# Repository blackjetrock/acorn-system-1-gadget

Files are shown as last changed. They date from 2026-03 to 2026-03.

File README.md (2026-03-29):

# Acorn System One Gadget

This is a small gadget that attaches to an Acorn System One. It is a Pico XL RP2350 with 48 GPIOs attached to the
expansion bus of the System One

* 60K of memory. The RP2350 emulates RAM everywhere in the memory space apart from block 0
* Tracing of addresses as code executes. This is a crude trace at the moment, but could be expanded.
* Loading of binary files from SD card into memory. For instance the monitor can be loaded from SD card and run from RAM.
* Snapshot of the entire 64K memory to an SD card file.
* A USB CLI that can drive the gadget
* An OLED display and three keys, these do nothing at the moment.
* Reset from the USB CLI
* Powering of the System One from the USB supply of the Pico. The regulator has to be removed for this to work. Power can
  come from a host computer if the USB CLI is used, or a battery power pack for portability.



On a system 1 you can load a slightly modified COS and BASIC into memory and run it:



The COS is modified to move the 6522 into RAM so that the keyboard can be driven from the USB CLI. The screen is captured by reading screen memory and also emulating som eof the functions of the 6845 CRT controller.

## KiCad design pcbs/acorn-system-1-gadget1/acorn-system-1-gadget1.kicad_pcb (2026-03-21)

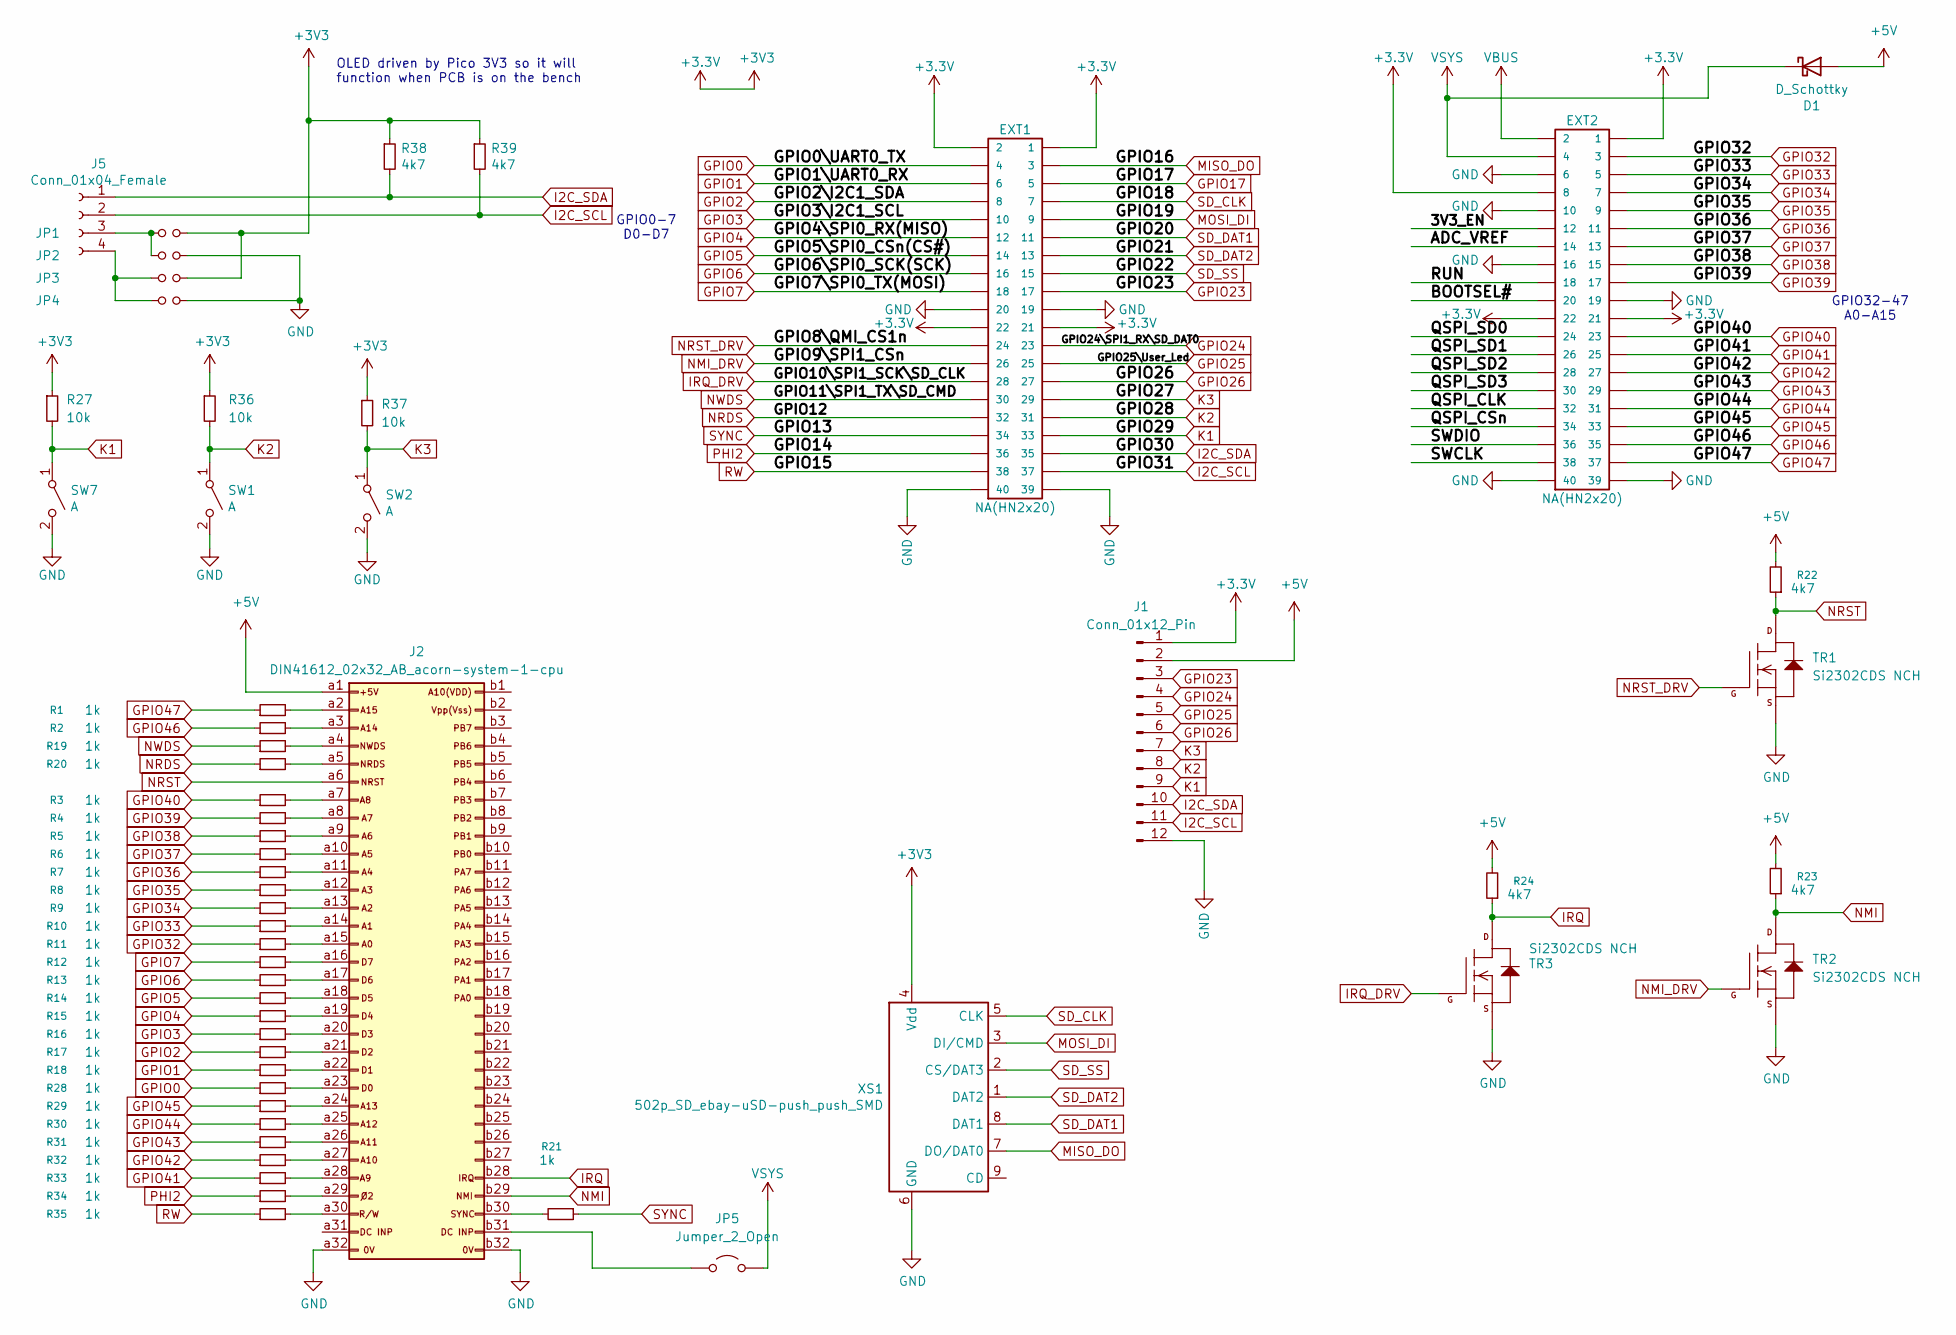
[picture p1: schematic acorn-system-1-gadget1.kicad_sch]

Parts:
D1: D_Schottky; D_SOD-123
EXT1, EXT2: NA(HN2x20); PinSocket_2x20_P2.54mm_Vertical
J1: Conn_01x12_Pin; PinHeader_1x12_P2.54mm_Vertical
J2: DIN41612_02x32_AB_acorn-system-1-cpu; DIN41612_Q_2x32_Female_Horizontal_THT
J5: Conn_01x04_Female; PinHeader_1x04_P2.54mm_Vertical
JP1, JP2, JP3, JP4: Jumper_NO_Small; SolderJumper-2_P1.3mm_Open_TrianglePad1.0x1.5mm
JP5: Jumper_2_Open; PinHeader_1x02_P2.54mm_Vertical
R1, R2, R3, R4, R5, R6, R7, R8, R9, R10, R11, R12, R13, R14, R15, R16, R17, R18, R19, R20, R21, R28, R29, R30, R31, R32, R33, R34, R35: 1k; R_0805_2012Metric_Pad1.20x1.40mm_HandSolder
R22, R23, R24, R38, R39: 4k7; R_0805_2012Metric_Pad1.20x1.40mm_HandSolder
R27, R36, R37: 10k; R_0805_2012Metric
SW1, SW2, SW7: A; SW_PUSH_6mm
TR1, TR2, TR3: Si2302CDS NCH; SOT-23
XS1: 502p_SD_ebay-uSD-push_push_SMD; Conn_uSDcard

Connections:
+3.3V: EXT1.1, EXT1.2, EXT1.21, EXT1.22, EXT2.1, EXT2.8, EXT2.21, EXT2.22, J1.1, JP1.2, JP3.2, R27.1, R36.1, R37.1, R38.1, R39.1, XS1.4 (Vdd)
+5V: D1.2 (A), J1.2, J2.a1, R22.2, R23.2, R24.2
/3V3_EN: EXT2.12
/ADC_VREF: EXT2.14
/BOOTSEL#: EXT2.20
/QSPI_CLK: EXT2.32
/QSPI_CSn: EXT2.34
/QSPI_SD0: EXT2.24
/QSPI_SD1: EXT2.26
/QSPI_SD2: EXT2.28
/QSPI_SD3: EXT2.30
/RUN: EXT2.18
/SWCLK: EXT2.38
/SWDIO: EXT2.36
GND: EXT1.19, EXT1.20, EXT1.39, EXT1.40, EXT2.6, EXT2.10, EXT2.16, EXT2.19, EXT2.39, EXT2.40, J1.12, J2.a32, J2.b32, JP2.2, JP4.2, SW1.2 (B), SW2.2 (B), SW7.2 (B), TR1.2 (S), TR2.2 (S), TR3.2 (S), XS1.6 (GND)
GPIO0: EXT1.4, R28.1
GPIO1: EXT1.6, R18.1
GPIO2: EXT1.8, R17.1
GPIO3: EXT1.10, R16.1
GPIO4: EXT1.12, R15.1
GPIO5: EXT1.14, R14.1
GPIO6: EXT1.16, R13.1
GPIO7: EXT1.18, R12.1
GPIO17: EXT1.5
GPIO23: EXT1.17, J1.3
GPIO24: EXT1.23, J1.4
GPIO25: EXT1.25, J1.5
GPIO26: EXT1.27, J1.6
GPIO32: EXT2.3, R11.1
GPIO33: EXT2.5, R10.1
GPIO34: EXT2.7, R9.1
GPIO35: EXT2.9, R8.1
GPIO36: EXT2.11, R7.1
GPIO37: EXT2.13, R6.1
GPIO38: EXT2.15, R5.1
GPIO39: EXT2.17, R4.1
GPIO40: EXT2.23, R3.1
GPIO41: EXT2.25, R33.1
GPIO42: EXT2.27, R32.1
GPIO43: EXT2.29, R31.1
GPIO44: EXT2.31, R30.1
GPIO45: EXT2.33, R29.1
GPIO46: EXT2.35, R2.1
GPIO47: EXT2.37, R1.1
I2C_SCL: EXT1.37, J1.11, J5.2, R39.2
I2C_SDA: EXT1.35, J1.10, J5.1, R38.2
IRQ: J2.b28, R24.1, TR3.3 (D)
IRQ_DRV: EXT1.28, TR3.1 (G)
K1: EXT1.33, J1.9, R27.2, SW7.1 (A)
K2: EXT1.31, J1.8, R36.2, SW1.1 (A)
K3: EXT1.29, J1.7, R37.2, SW2.1 (A)
MISO_DO: EXT1.3, XS1.7 (DO/DAT0)
MOSI_DI: EXT1.9, XS1.3 (DI/CMD)
NMI: J2.b29, R23.1, TR2.3 (D)
NMI_DRV: EXT1.26, TR2.1 (G)
NRDS: EXT1.32, R20.1
NRST: J2.a6, R22.1, TR1.3 (D)
NRST_DRV: EXT1.24, TR1.1 (G)
NWDS: EXT1.30, R19.1
unnamed: J2.a2, R1.2
unnamed: J2.a3, R2.2
unnamed: J2.a4, R19.2
unnamed: J2.a5, R20.2
unnamed: J2.a7, R3.2
unnamed: J2.a8, R4.2
unnamed: J2.a9, R5.2
unnamed: J2.a10, R6.2
unnamed: J2.a11, R7.2
unnamed: J2.a12, R8.2
unnamed: J2.a13, R9.2
unnamed: J2.a14, R10.2
unnamed: J2.a15, R11.2
unnamed: J2.a16, R12.2
unnamed: J2.a17, R13.2
unnamed: J2.a18, R14.2
unnamed: J2.a19, R15.2
unnamed: J2.a20, R16.2
unnamed: J2.a21, R17.2
unnamed: J2.a22, R18.2
unnamed: J2.a23, R28.2
unnamed: J2.a24, R29.2
unnamed: J2.a25, R30.2
unnamed: J2.a26, R31.2
unnamed: J2.a27, R32.2
unnamed: J2.a28, R33.2
unnamed: J2.a29, R34.2
unnamed: J2.a30, R35.2
unnamed: J2.b30, R21.2
unnamed: J2.b31, JP5.1 (A)
unnamed: J5.3, JP1.1, JP2.1
unnamed: J5.4, JP3.1, JP4.1
PHI2: EXT1.36, R34.1
RW: EXT1.38, R35.1
SD_CLK: EXT1.7, XS1.5 (CLK)
SD_DAT1: EXT1.11, XS1.8 (DAT1)
SD_DAT2: EXT1.13, XS1.1 (DAT2)
SD_SS: EXT1.15, XS1.2 (CS/DAT3)
SYNC: EXT1.34, R21.1
VBUS: EXT2.2
VSYS: D1.1 (K), EXT2.4, JP5.2 (B)

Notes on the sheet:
OLED driven by Pico 3V3 so it will function when PCB is on the bench
GPIO0-7 D0-D7
GPIO32-47 A0-A15

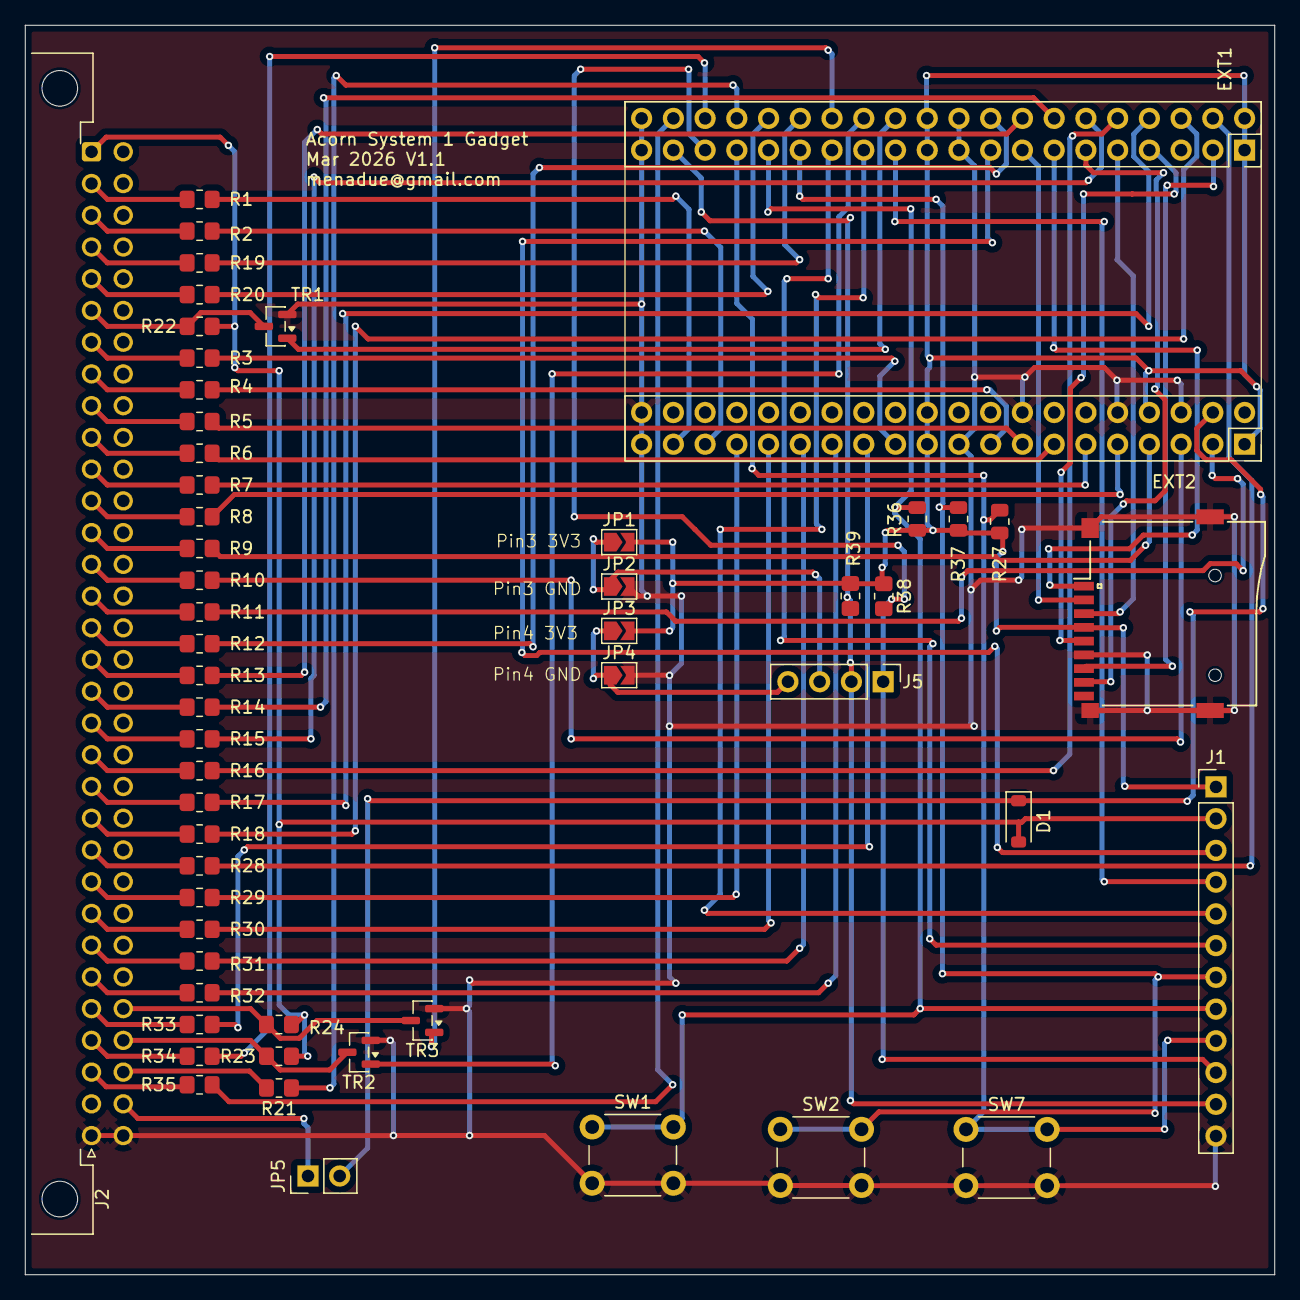
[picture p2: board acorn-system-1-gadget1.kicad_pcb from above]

Board: 2 copper layers, 100.0 x 100.0 mm, 55 parts (0 on the bottom side), 86 nets.

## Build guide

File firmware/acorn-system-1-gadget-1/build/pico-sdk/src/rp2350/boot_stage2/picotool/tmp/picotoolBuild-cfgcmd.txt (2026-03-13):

cmd='/usr/bin/cmake;--no-warn-unused-cli;-DCMAKE_MAKE_PROGRAM:FILEPATH=/usr/bin/gmake;-DPICO_SDK_PATH:FILEPATH=/home/menadue/pico/pico-sdk;-DPICOTOOL_NO_LIBUSB=1;-DPICOTOOL_FLAT_INSTALL=1;-DCMAKE_INSTALL_PREFIX=/home/menadue/tree/github/acorn-system-1-gadget/firmware/acorn-system-1-gadget-1/build/_deps;-DCMAKE_RULE_MESSAGES=OFF;-DCMAKE_INSTALL_MESSAGE=NEVER;-GUnix Makefiles;-S;<SOURCE_DIR><SOURCE_SUBDIR>;-B;<BINARY_DIR>'

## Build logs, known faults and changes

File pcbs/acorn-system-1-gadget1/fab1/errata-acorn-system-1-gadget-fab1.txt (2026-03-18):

1. Signals to SD card holder reversed.
2. Run BUS power to edge connector through jumper for USB power ption.

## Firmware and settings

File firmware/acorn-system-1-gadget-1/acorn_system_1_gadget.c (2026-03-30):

//////////////////////////////////////////////////////////////////////////////
//
// Acorn System 1 Memory Emulator
//
////////////////////////////////////////////////////////////////////////////////
//
// Emulates memory
//
// Set up to emulate 60K of memory, only page 0 is not emulated.
// PROMs removed and emulated
//
//
////////////////////////////////////////////////////////////////////////////////

#include "switches.h"
#include "version.h"

#pragma GCC diagnostic ignored "-Wwrite-strings"

#include <ctype.h>
#include <math.h>
#include <stdarg.h>
#include <stdio.h>
#include <stdlib.h>
#include <string.h>
#include <stdint.h>

#include "pico/stdlib.h"
#include "hardware/pio.h"
#include "hardware/dma.h"
#include "hardware/irq.h"
#include "hardware/flash.h"
#include "hardware/clocks.h"
#include "hardware/structs/bus_ctrl.h"

#define DEBUG_STOP_LOOP while(1) {}

// Some logic to analyse:

#include "hardware/structs/pwm.h"
#include "pico/multicore.h"
#include "pico/bootrom.h"

#include "oled.h"
#include "sdcard.h"

#include "menu.h"

////////////////////////////////////////////////////////////////////////////////

#define MAX_FILE_LINE 200

////////////////////////////////////////////////////////////////////////////////
//
#define ACORN_PORTD   0x2E21

////////////////////////////////////////////////////////////////////////////////
//
// VDU registers
#define NUM_VDU_REGS 20

volatile uint8_t vdu_reg[NUM_VDU_REGS];
volatile uint8_t vdu_addr = 0xcc;

#define VDU_REG_HOR_DISP  1
#define VDU_REG_VER_DISP  6

#define VDU_REG_STARTH   12
#define VDU_REG_STARTL   13
#define VDU_REG_CURSRH   14
#define VDU_REG_CURSRL   15

#define VDU_START_ADDRESS (vdu_reg[VDU_REG_STARTH]*256+vdu_reg[VDU_REG_STARTL])
#define VDU_CURSR_ADDRESS (vdu_reg[VDU_REG_CURSRH]*256+vdu_reg[VDU_REG_CURSRL])
#define VDU_NUM_CHARS     (vdu_reg[VDU_REG_HOR_DISP]*vdu_reg[VDU_REG_VER_DISP])

////////////////////////////////////////////////////////////////////////////////
//
// Tracing of processor accesses
//

#define TRACE_ON 1

// How many addresses are traced
#define TRACE_N   32

volatile int trace_i = 0;
volatile int trace_running = 0;

volatile uint16_t trace_addr[TRACE_N];
volatile uint8_t trace_value[TRACE_N];
volatile char trace_type[TRACE_N];

////////////////////////////////////////////////////////////////////////////////

void prompt(void);
void serial_help(void);

////////////////////////////////////////////////////////////////////////////////

// How much RAM to display 
#define RAM_SIZE 1024

// Shadow of entire memory space
#define MEM_SIZE 65536

volatile uint8_t mem_data[MEM_SIZE];

#define ADDRESS_MASK  0xFFFF
#define WINDOW_START  0x8000

////////////////////////////////////////////////////////////////////////////////



////////////////////////////////////////////////////////////////////////////////

// Value that can be set from the keyboard
// Can be entered as hex or decimal

#define PAR_TYPE_DEC 0

int parameter = 0;
int keypress = 0;

#define TEXT_PARAMETER_LEN 40
char text_parameter[TEXT_PARAMETER_LEN+1] = "";

////////////////////////////////////////////////////////////////////////////////
//
// GPIOs
//

const int PIN_D0        =  0;
const int PIN_D1        =  1;
const int PIN_D2        =  2;
const int PIN_D3        =  3;
const int PIN_D4        =  4;
const int PIN_D5        =  5;
const int PIN_D6        =  6;
const int PIN_D7        =  7;

const int PIN_NRST_DRV  =  8;
const int PIN_NMI_DRV   =  9;
const int PIN_IRQ_DRV   =  10;
const int PIN_NWDS      =  11;
const int PIN_NRDS      =  12;
const int PIN_SYNC      =  13;
const int PIN_PHI2      =  14;
const int PIN_RW        =  15;

#define PIN_BITNUM_NWDS    11
#define PIN_BITNUM_NRDS    12

// SD card GPIOs here
const int PIN_K3        =  27;
const int PIN_K2        =  28;
const int PIN_K1        =  29;


const int PIN_A0        =  32;
const int PIN_A1        =  33; 
const int PIN_A2        =  34; 
const int PIN_A3        =  35; 
const int PIN_A4        =  36; 
const int PIN_A5        =  37; 
const int PIN_A6        =  38; 
const int PIN_A7        =  39; 
const int PIN_A8        =  40; 
const int PIN_A9        =  41; 
const int PIN_A10       =  42; 
const int PIN_A11       =  43; 
const int PIN_A12       =  44; 
const int PIN_A13       =  45; 
const int PIN_A14       =  46; 
const int PIN_A15       =  47; 


////////////////////////////////////////////////////////////////////////////////
//
// Chris oddy display
//

uint8_t app1[] =
  {
    0xa2, 0x07, 0xbd, 0x10, 0x80, 0x95, 0x10, 0xca, 0x10, 0xf8, 0x20, 0x0c, 0xfe, 0x4c, 0xfb, 0xfe,
    0x00, 0x77, 0x58, 0x5c, 0x50, 0x54, 0x00, 0x30,
  };


//------------------------------------------------------------------------------

uint8_t *app_list[] =
  {
    app1,
  };

////////////////////////////////////////////////////////////////////////////////

void set_gpio_output(const int gpio)
{
  gpio_init(gpio);
  gpio_set_dir(gpio, GPIO_OUT);
}

void set_gpio_input(const int gpio)
{
  gpio_init(gpio);
  gpio_set_dir(gpio, GPIO_IN);
}

////////////////////////////////////////////////////////////////////////////////

////////////////////////////////////////////////////////////////////////////////

void run_mount(void) {
  //    const char *arg = chk_dflt_log_drv(argc, argv);
  const char *arg = "0:";
  if (!arg)
        return;
    sd_card_t *sd_card_p = sd_get_by_drive_prefix(arg);
    if (!sd_card_p) {
        printf("Unknown logical drive id: \"%s\"\n", arg);
        return;
    }
    FATFS *fs_p = &sd_card_p->state.fatfs;
    FRESULT fr = f_mount(fs_p, arg, 1);
    if (FR_OK != fr) {
        printf("f_mount error: %s (%d)\n", FRESULT_str(fr), fr);
        return;
    }
    sd_card_p->state.mounted = true;
}

void run_unmount(void) {
  //    const char *arg = chk_dflt_log_drv(argc, argv);
  const char *arg = "0:";
  
  if (!arg)
        return;

    sd_card_t *sd_card_p = sd_get_by_drive_prefix(arg);
    if (!sd_card_p) {
        printf("Unknown logical drive id: \"%s\"\n", arg);
        return;
    }    
    FRESULT fr = f_unmount(arg);
    if (FR_OK != fr) {
        printf("f_unmount error: %s (%d)\n", FRESULT_str(fr), fr);
        return;
    }
    sd_card_p->state.mounted = false;
    sd_card_p->state.m_Status |= STA_NOINIT;  // in case medium is removed
}

////////////////////////////////////////////////////////////////////////////////

void display_ram_at(uint8_t *dat)
{
  printf("\n");
  
  for(int z = 0; z<RAM_SIZE; z++)
    {
      int byte = 0;
      
      if( (z % 8) == 0)
	{
	  printf("\n%03X: ", z);
	}
      
      printf("%02X ", *(dat++));
    }
  
  printf("\n");

}

////////////////////////////////////////////////////////////////////////////////
//
// Flash data
//
// We have several flash program slots.
// Slots are in the top 1Mbyte of flash
//
// The flash has to be erased in 4096 byte aligned blocks
// Writes can be 256 byte aligned but due to erase being 4096 we use that slot size.

// Program and dat aram is stored at the same time, so it is a snapshot of the entire
// RAM. RAM plkus program is 256 bytes.


#define FLASH_PROGRAM_DATA_SIZE         256
#define FLASH_PROGRAM_SLOT_SIZE         4096
#define FLASH_PROGRAM_SLOT_AREA_SIZE    (1000*1024)
#define FLASH_PROGRAM_NUM_SLOTS         (FLASH_PROGRAM_SLOT_AREA_SIZE / FLASH_PROGRAM_SLOT_SIZE)

#define FLASH_SLOT_OFFSET (1024*1024)
uint8_t *flash_slot_contents   = (uint8_t *) (XIP_BASE + FLASH_SLOT_OFFSET);

// general buffer for flash read and write
uint8_t slot_buffer[FLASH_PROGRAM_DATA_SIZE];


////////////////////////////////////////////////////////////////////////////////
//
// Flash write/erase
//
////////////////////////////////////////////////////////////////////////////////

// Erase a slot
void erase_slot(int n)
{
  flash_range_erase(FLASH_SLOT_OFFSET+n*FLASH_PROGRAM_SLOT_SIZE, FLASH_PROGRAM_SLOT_SIZE);
}

// Checksum a slot
int checksum_slot(int slot_num)
{
  int csum = 0;

  for(int i=0; i<FLASH_PROGRAM_DATA_SIZE; i++)
    {
      csum += *(flash_slot_contents+slot_num*FLASH_PROGRAM_SLOT_SIZE+i);
    }

  return(csum);
}
void cli_erase_program_slot(void)
{
  printf("\nErasing program slot %d...", parameter);
  erase_slot(parameter);
  printf("\ndone.\n");
}

void cli_display_program_slot(void)
{
  
  printf("\nSlot %d\n", parameter);

  // First dump in hex
  display_ram_at(flash_slot_contents+parameter*FLASH_PROGRAM_SLOT_SIZE);

  printf("\n\n");
}

void cli_display_vdu_regs(void)
{
  printf("\nVDU Regs\n");

  printf("\nVDU_START:     %04X", VDU_START_ADDRESS);
  printf("\nVDU_NUM_CHARS: %04X (%d)", VDU_NUM_CHARS, VDU_NUM_CHARS);
  
  printf("\nAddr:%02X", vdu_addr);

  for(int i=0; i<NUM_VDU_REGS; i++)
    {
      printf("\n%02X:%02X", i, vdu_reg[i]);
    }

  printf("\n");
}


////////////////////////////////////////////////////////////////////////////////


void cli_get_vdu(void)
{
  // Display the VDU screen area
  //

  printf("\n/--------------------------------------------------------------------------------\\");
  
  for(int i=0; i< 2000; i++)
    {
      if( (i % 80) == 0 )
        {
          if( i != 0 )
            {
              printf("|");
            }
          
          printf("\n|");
        }
      
      printf("%c", mem_data[0x1000+i]);
    }

  printf("|\n\\--------------------------------------------------------------------------------/");
  printf("\n");
}
////////////////////////////////////////////////////////////////////////////////

uint8_t screen[8192];

int cursor_on = 1;
int cursor_counter = 0;

void update_screen(void)
{
  // Cursor Position (Row, Col): ESC [ <row>;<col> H (e.g., 10,10)
  // Save Cursor Position: ESC 7 (DECSC)
  // Restore Cursor Position: ESC 8 (DECRC)

  cursor_counter++;

  if( cursor_counter > 12 )
    {
      cursor_on = !cursor_on;
      cursor_counter = 0;
    }
  
  // Compare screen buffer with memory, update any changes
  int x = 0;
  int y = 0;

  int vdu_start = VDU_START_ADDRESS;
  int vdu_addr = (vdu_start & 0x07FF) | 0x1000;
  int cur_addr = (VDU_CURSR_ADDRESS & 0x07FF) | 0x1000;
  
  printf("%c7", 27);
  printf("%c[?25l", 27);
  
  for(int i=0; i< 2000; i++)
    {
      if( mem_data[vdu_addr] != screen[i],1 )
        {

          printf("%c[%d;%dH", 27, y+2, x+2);
          if( cur_addr == vdu_addr )
            {
              if( cursor_on )
                {
                  printf("%c", '_');
                }
              else
                {
                  printf("%c", mem_data[vdu_addr]);
                }
            }
          else
            {
              printf("%c", mem_data[vdu_addr]);
            }
          
          //screen[i] = mem_data[vdu_addr];
        }

      vdu_addr = ((vdu_addr+1) & 0x07ff) | 0X1000;

      x++;
      
      if( x >= 80 )
        {
          x = 0;
          y++;
        }
    }
  
  printf("%c8", 27);
  printf("%c[?25h", 27);
}

//------------------------------------------------------------------------------

void cli_vdu_loop(void)
{
  int done = 0;
  int  key;
  
  printf("\nVDU Loop...\n");

  for(int i=0; i<200; i++)
    {
      printf("\n");
    }
  
  // Inital screen display
  
  cli_get_vdu();
  
  while(!done)
    {
      update_screen();
      
      if( ((key = getchar_timeout_us(1000)) != PICO_ERROR_TIMEOUT))
        {
          switch(key)
            {
            case '_':
              cli_get_vdu();
              break;
              
            case 27:
              done = 1;            
              printf("\nExit from VDU Loop\n");
              break;

            default:
              // Send to Acorn
              mem_data[ACORN_PORTD] = key | 0x80;
              sleep_us(100);
              mem_data[ACORN_PORTD] = key;
              break;
            }
	}
    }
}

////////////////////////////////////////////////////////////////////////////////
//
// Load app, index is parameter
//

void cli_load_app(void)
{
  uint8_t *app_ptr;
  int num_apps = (sizeof(app_list) / sizeof(uint8_t *));
  
  printf("\n%d apps", num_apps);
  
  if( (parameter >= 0) && (parameter < num_apps) )
    {
      app_ptr = app_list[parameter];
      
      memcpy((void *)&(mem_data[0x8000]), (void *)app_list[parameter], sizeof(app1));

      printf("\nLoaded app %d", parameter);
    }
  else
    {
      printf("\nParameter out of range");
    }
  

}

////////////////////////////////////////////////////////////////////////////////

void cli_boot_mass(void)
{
  reset_usb_boot(0,0);
}

void cli_do_reset(void)
{
  printf("\nResetting...");
  gpio_put(PIN_NRST_DRV, 1);
  sleep_ms(50);
  gpio_put(PIN_NRST_DRV, 0);

  printf("\nDone");
  
}
////////////////////////////////////////////////////////////////////////////////
//
// Scans the directory and works out the next file number to use
//
// Leaves max_filenum with that value
//
////////////////////////////////////////////////////////////////////////////////

#define FILE_NAME_FORMAT "as1%04d.bin"
#define INFO_FILE_NAME_FORMAT "as1%04d.inf"

#define FILE_NAME_SCAN   "as1%d.bin"
#define FILE_NAME_GLOB   "as1*.bin"

int find_next_file_number(void)
{
  int file_n = 0;
  int num_listfiles = 0;
  int i;
  
  char cwdbuf[FF_LFN_BUF] = {0};
  FRESULT fr;
  char const *p_dir;

  //DEBUG_STOP;

  printf("\nAttempting to cd to directory...");
  if( !cd_to_dir(FILES_DIR) )
    {
      unmount_sd();
      return(0);
    }

  printf("\nGetting cwd...");
  fr = f_getcwd(cwdbuf, sizeof cwdbuf);

  // printf will print to console
  if (FR_OK != fr)
    {
      printf("f_getcwd error: %s (%d)\n", FRESULT_str(fr), fr);
      return(0);
    }
  
  p_dir = cwdbuf;

  printf("\nFile num search: %s\n", p_dir);
  
  DIR dj;      /* Directory object */
  FILINFO fno; /* File information */

  memset(&dj, 0, sizeof dj);
  memset(&fno, 0, sizeof fno);

  max_filenum = 0;
  
  fr = f_findfirst(&dj, &fno, p_dir, FILE_NAME_GLOB);

  if (FR_OK != fr)
    {
      printf("f_findfirst error: %s (%d)\n", FRESULT_str(fr), fr);
      return(0);
    }
  
  while( (fr == FR_OK) && fno.fname[0])
    { 
      if (fno.fattrib & AM_DIR)
	{
	  // Directory, we ignore these
	}
      else
	{
	  int filenum;
	  sscanf(fno.fname, FILE_NAME_SCAN, &filenum);

	  if( filenum > max_filenum )
	    {
	      max_filenum = filenum;
	    }
	}
       
      fr = f_findnext(&dj, &fno); /* Search for next item */
    }
  
  f_closedir(&dj);

  printf("\nFound next file number %d", max_filenum);
  return(1);
}

////////////////////////////////////////////////////////////////////////////////
//
// Writes the buffer to a file.
// Deletes any file that exists with the same name so that the resulting
// file is the same size as the buffer
// Searches the card directory for the highest file number and uses the next one
//
////////////////////////////////////////////////////////////////////////////////

void core_writefile(int address, int length)
{
  char filename[20];
  char info_filename[20];
  int i;
  FRESULT fr;
  FIL fp;
  size_t bytes_written = 0;
  char line[40];

  //DEBUG_STOP

  printf("\nWriting file to SD card");
  mount_sd();

  if( !cd_to_dir(FILES_DIR) )
    {
      unmount_sd();
      return;
    }

  find_next_file_number();
  sprintf(filename,      FILE_NAME_FORMAT,      ++max_filenum);
  sprintf(info_filename, INFO_FILE_NAME_FORMAT,   max_filenum);

  printf("\nWriting to %s", filename);
  
  oled_clear_display(&oled0);
  oled_set_xy(&oled0, 0, 0);
  oled_display_string(&oled0, "Writing");
  oled_set_xy(&oled0, 0, 8);
  oled_display_string(&oled0, filename);
  
  // Open file for writing
  fr = f_open(&fp, filename, FA_CREATE_NEW | FA_WRITE);

  if (FR_OK != fr && FR_EXIST != fr)
    {
      printf("\nOpen error");
      //      oled_error("Open error");
      unmount_sd();
      return;
    }

  printf("\nWriting data...");

  // Split up into smaller chunks
  int length_to_go = length;
  int addr = address;

#define CHUNK_SIZE 32
  
  while( length_to_go > 0 )
    {
      if( length_to_go > CHUNK_SIZE )
        {
          printf("\nWriting %d bytes at %04X", CHUNK_SIZE, addr);
          f_write (&fp, (uint8_t *)&(mem_data[addr]), CHUNK_SIZE, &bytes_written);
          length_to_go -= CHUNK_SIZE;
          addr += CHUNK_SIZE;
          printf(" %ld bytes written");
        }
      else
        {
          printf("\nWriting %d bytes at %04X", length_to_go, addr);
          f_write (&fp, (uint8_t *)&(mem_data[addr]), length_to_go, &bytes_written);
          length_to_go = 0;
          addr += length_to_go;
          printf(" %ld bytes written");
        }
    }
  
  
  fr = f_close(&fp);
  if (FR_OK != fr)
    {
      printf("f_close error: %s (%d)\n", FRESULT_str(fr), fr);
      unmount_sd();
      return;
    }

  //------------------------------------------------------------------------------
  //
  // Now write an info file to go with the data
  // Open file for writing
  fr = f_open(&fp, info_filename, FA_CREATE_NEW | FA_WRITE);

  if (FR_OK != fr && FR_EXIST != fr)
    {
      printf("\nOpen error");
      //      oled_error("Open error");
      unmount_sd();
      return;
    }

  printf("\nWriting data...");

  // Write the entire buffer in one go
  f_printf(&fp, "\n*ADDRESS:0000");
  f_printf(&fp, "\n*LENGTH:%04X", MEM_SIZE);
  
  fr = f_close(&fp);
  if (FR_OK != fr)
    {
      printf("f_close error: %s (%d)\n", FRESULT_str(fr), fr);
      unmount_sd();
      return;
    }

  oled_set_xy(&oled0, 0, 3*8);
  sprintf(line, "%d bytes", bytes_written);
  oled_display_string(&oled0, line);

  unmount_sd();

  printf("\nDone.\n");
}
//------------------------------------------------------------------------------
//
// Save all of memory to SD card
//

void cli_snapshot_memory(void)
{
  core_writefile(0x0000, MEM_SIZE);
}
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
int main(void)
{
#if 0
  // Do nothing, GPIOs all inputs
  while(1)
    {
    }
#endif
  
  ////////////////////////////////////////////////////////////////////////////////
  // Set up GPIOs
  set_gpio_input(PIN_D0);
  set_gpio_input(PIN_D1);
  set_gpio_input(PIN_D2);
  set_gpio_input(PIN_D3);
  set_gpio_input(PIN_D4);
  set_gpio_input(PIN_D5);
  set_gpio_input(PIN_D6);
  set_gpio_input(PIN_D7);
  
  set_gpio_output(PIN_NRST_DRV);
  set_gpio_output(PIN_NMI_DRV);
  set_gpio_output(PIN_IRQ_DRV);
  set_gpio_input(PIN_NWDS);
  set_gpio_input(PIN_NRDS);
  set_gpio_input(PIN_SYNC);
  set_gpio_input(PIN_PHI2);
  set_gpio_input(PIN_RW);

  // SD card GPIOs here
  set_gpio_input(PIN_K3);
  set_gpio_input(PIN_K2);
  set_gpio_input(PIN_K1);


  set_gpio_input(PIN_A0);
  set_gpio_input(PIN_A1);
  set_gpio_input(PIN_A2);
  set_gpio_input(PIN_A3);
  set_gpio_input(PIN_A4);
  set_gpio_input(PIN_A5);
  set_gpio_input(PIN_A6);
  set_gpio_input(PIN_A7);
  set_gpio_input(PIN_A8);
  set_gpio_input(PIN_A9);
  set_gpio_input(PIN_A10);
  set_gpio_input(PIN_A11);
  set_gpio_input(PIN_A12);
  set_gpio_input(PIN_A13);
  set_gpio_input(PIN_A14);
  set_gpio_input(PIN_A15);
  
  // Set outputs to safe levels
  
  gpio_put(PIN_NRST_DRV, 0);
  gpio_put(PIN_NMI_DRV, 0);
  gpio_put(PIN_IRQ_DRV, 0);
  
  ////////////////////////////////////////////////////////////////////////////////
  //
  // Overclock as needed
  //
  ////////////////////////////////////////////////////////////////////////////////
  
  //#define OVERCLOCK 135000
  //#define OVERCLOCK 200000
#define OVERCLOCK 270000
  //#define OVERCLOCK 360000
  
#if OVERCLOCK > 270000
  /* Above this speed needs increased voltage */
  vreg_set_voltage(VREG_VOLTAGE_1_20);
  sleep_ms(1000);
#endif
  
  /* Overclock */
  set_sys_clock_khz( OVERCLOCK, 1 );

  //stdio_init_all();
  stdio_usb_init();

  // Run the shift register touch key scanning on the second core
  multicore_launch_core1(ram_emulate);

  //sleep_ms(3000);

  printf("\n");
  printf("\n                                  ********************************************");
  printf("\n                                  *        Acorn System 1 Gadget             *");
  printf("\n                                  ********************************************");
  printf("\n");
  printf("\nVersion:1.1.%d Compile time:%s %s", VERSION_INC, __DATE__, __TIME__);
  printf("\n");
  
#if OLED_ON
  // Set up OLED display
  i2c_init(&i2c_bus_0);
  
  oled_setup(&oled0);
#endif
  
  // Sets sd_ok flag for later use
#if SD_ON   

  printf("\nInitialising SD card driver...");

#define SD_CARD 1

  // Initialise SD card driver
  sd_init_driver();

  // Mount and unmount the SD card to set the sd_ok_flag up
  mount_sd();
  unmount_sd();
  
  oled_set_xy(&oled0, 0,21);
  if( sd_ok_flag )
    {
      oled_display_string(&oled0, "SD card OK");
      printf("\nSD card OK");
    }
  else
    {
      oled_display_string(&oled0, "SD card NOT OK");
      printf("\nSD card NOT OK");
    }

  mount_sd();
  if( !cd_to_dir(FILES_DIR) )
    {
      printf("\nFailed to cd to %s directory", FILES_DIR);
      printf("\n%s", sd_error);
    }
  else
    {
      printf("\n%s directory found", FILES_DIR);
    }
  unmount_sd();

  sleep_ms(1000);
#endif

#if OLED_ON
  // Overall loop, which contains the polling loop and the menu loop
  oled_clear_display(&oled0);
  
  oled_set_xy(&oled0, 5, 0);
  oled_display_string(&oled0, "Acorn System 1");

  oled_set_xy(&oled0, 5, 16);
  oled_display_string(&oled0, "Memory Emulator");

#endif

  // Run the shift register touch key scanning on the second core
  //  multicore_launch_core1(core1_main);

  //------------------------------------------------------------------------------
  
  // Set up the OLED menu
  
  current_menu = (struct MENU_ELEMENT *) &(home_menu[0]);
  last_menu    = (struct MENU_ELEMENT *) &(home_menu[0]);
  the_home_menu = last_menu;

  //to_home_menu(NULL);

  //  init_buttons();

  //------------------------------------------------------------------------------
  // Load the monitor
  
  cli_load_monitor();
  
  //------------------------------------------------------------------------------
  
  while(1)
    {
#if DEBUG_LOOP
      printf("\nLoop");
#endif
      
      serial_loop();

    }
}
